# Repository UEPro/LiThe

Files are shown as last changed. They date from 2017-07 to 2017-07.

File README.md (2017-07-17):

# LiThe
Lichttheremin / Light-Theremin<br />

This PCB was designed for a Workshop in Germany, thus the documentation is in German. Contact me if you need a translation (Contact info in folder "Documentation", file "Anleitung_LiThe")

<b>AKF-WORKSHOP:</b></n>

Hallo ihr Lieben, ich hoffe ihr hattet alle ein tolles Festival und seid gut Heim gekommen. :)

Vielen Dank, dass ihr beim Workshop mitgemacht habt. Es hat mir riesigen Spaß gemacht, mit euch zu Arbeiten und ich hoffe auch ihr hattet Freude am basteln.

Solltet ihr irgendwelche Fragen oder Probleme haben, schreibt mir einfach über github oder schickt mir eine E-Mail (die Adresse steht in der Anleitung oben im Ordner "Documentation").

Ich werde außerdem eine Facebookseite einrichten, damit ihr mich einfacher kontaktieren könnt. Der Link dazu kommt dann hier her.

Schreibt mir gerne auch für weiteres Feedback und Vorschläge.

Nochmals Danke für die tolle Zeit mit euch und das nette Feedback :) Ich hoffe man sieht sich wieder.

Downloadanleitung:<br />
-Einzelne Datei: Rechtsklick auf die Datei → "Ziel speichern unter" anklicken<br />
-Ganzes Archiv: oben rechts den grünen Knopf "Clone or download" anklicken → "Download as ZIP" anklicken → ZIP Archiv entpacken

<br /><span xmlns:dct="http://purl.org/dc/terms/" property="dct:title">LiThe</span> by <a xmlns:cc="http://creativecommons.org/ns#" href="https://github.com/UEPro/" property="cc:attributionName" rel="cc:attributionURL">Useless Electronics Projects</a> is licensed under a <a rel="license" href="http://creativecommons.org/licenses/by-sa/4.0/">Creative Commons Attribution-ShareAlike 4.0 International License</a>.<br />

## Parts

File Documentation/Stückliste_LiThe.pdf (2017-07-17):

## Lichttheremin – Bill of Materials (github.com/UEPro/LiThe)

Type | Manufacturer | Model | Specification | Package | Value | N | Part-Nr | Designators
Resistor | Royal Ohm | Metal film resistor | 0,6W; 250V; 50ppm/K | THT-axial | 100 Ω ±1% | 1 MF006FF1000A50 | | R2
Resistor | Royal Ohm | Metal film resistor | 0,6W; 250V; 50ppm/K | THT-axial | 10 kΩ ±1% | 1 MF006FF1002A50 | | R4
Resistor | Royal Ohm | Metal film resistor | 125mW; 150V= | SMD-0805 | 100 kΩ ±1% | 1 0805S8F1003T5E | | R3
Resistor | Token | LDR | | THT-radial | | 1 PGM5649D | | R1
Potentiometer | Alps | R12L | log. stereo | THT-radial | 10 kΩ | 1 RK12L12C0A0G | | VR1
Capacitor | Kemet | MLCC | 50V; X7R | THT 100mil | 10 nF ±20% | 1 C315C103M5R5TA | | C2
Capacitor | Kemet | MLCC | 50V; X7R | THT 200mil | 100 nF ±10% | 1 C322C104K5R5TA | | C3
Capacitor | Kemet | Polyester Capacitor | 63VAC; 100VDC | THT 200mil | 100 nF ±10% | 1 R82EC3100DQ70K | | C1
Capacitor | Wima | Polyester Capacitor | 63VAC; 100VDC | THT 200mil | 2,2 µF ±10% | 2 | MKS2D042201N00KO 00 | C4-5
Capacitor | Nichicon | Electrolytic Capacitor | 16V; ø6,3mm | THT-radial | 220 µF ±20% | 1 UVZ1C221MED | | C6
Diode | Diotec | ZMM4.7 | Z-Diode; 0,5W | MiniMELF | 4,7 V | 1 ZMM4.7 | | D1
Diode | Optosupply | LED | cyan 3mm | THT-radial | | 1 OSC34L3131A | | D2
Transistor | Fairchild | FDN304 | P-Ch. MOSFET | SOT-23 | | 1 FDN304P | | Q1
IC | TI | NE555 | | DIP-8 | | 1 NE555P | | U1
Switch | Generic | | SPDT Slide Switch | THT-radial | | 1 | | S1
Connector | Generic | Pin header | 1x2pin | THT 100mil | | 1 | | J1, J3
Connector | Generic | Pin header connector | 1x2pin | THT 100mil | | 1
Connector | Generic | Crimp Contacts | Female | | | 2
Connector | Lumberg | | Stereo 3,5mm TRS-Jack | THT | | 1 1503 07 | | J2
Connector | Generic | Battery Clip | 9V-Block | | | 1
PCB | | | | | | 1
Case | Gainta | | | | | 1 G1068B
Speaker | NOS | | 8ohm | | | 1
Battery | Duracell | 9V Industrial | 6LR61 | | | 1

NB: These are the parts I have used, mostly because I had them in stock. Other parts with other values/tolerances or from other manufacturers may work just as well or even better.

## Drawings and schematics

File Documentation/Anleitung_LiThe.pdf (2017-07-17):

# Lichttheremin

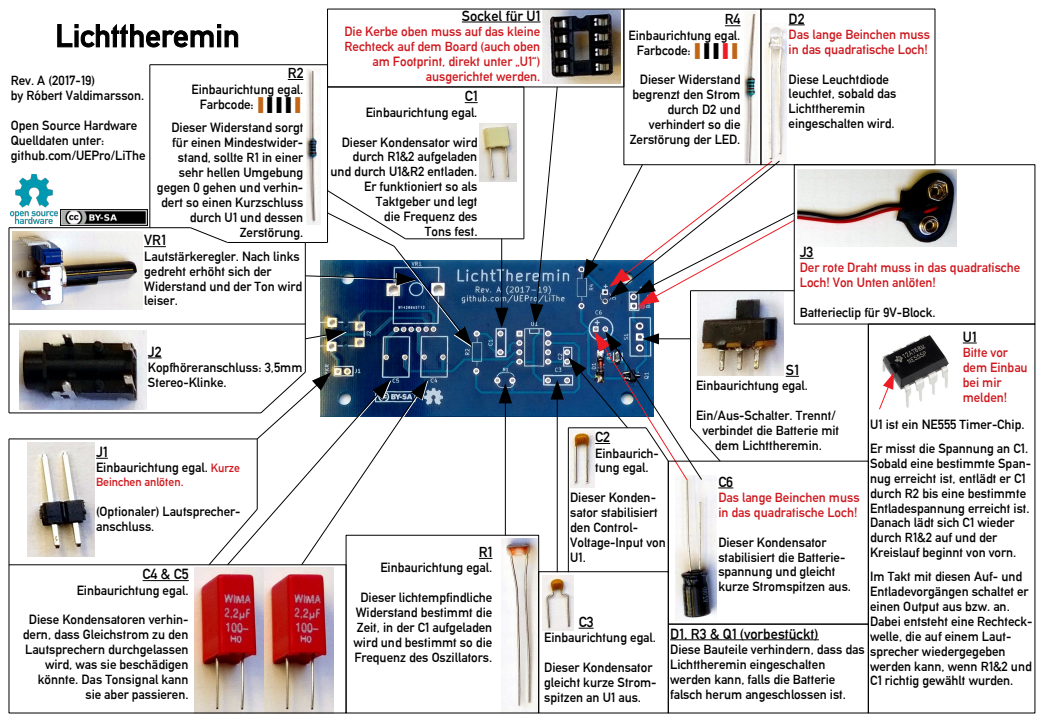
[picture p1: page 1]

Das lange Beinchen muss
in das quadratische Loch!

Die Kerbe oben muss auf das kleine
Rechteck auf dem Board (auch oben
am Footprint, direkt unter „U1“)

Einbaurichtung egal.
Farbcode:▐▐▐▐▐
Dieser Widerstand sorgt
für einen Mindestwider-
stand, sollte R1 in einer
sehr hellen Umgebung
gegen 0 gehen und verhin-
dert so einen Kurzschluss
durch U1 und dessen
Lautstärkeregler. Nach links
gedreht erhöht sich der
Widerstand und der Ton wird
leiser.

Open Source Hardware
Quelldaten unter:
github.com/UEPro/LiThe

Dieser Kondensator wird
durch R1&2 aufgeladen
und durch U1&R2 entladen.
Er funktioniert so als
Taktgeber und legt
die Frequenz des
Tons fest.

Der rote Draht muss in das quadratische
Loch! Von Unten anlöten!

Ein/Aus-Schalter. Trennt/
verbindet die Batterie mit
dem Lichttheremin.

U1 ist ein NE555 Timer-Chip.
Er misst die Spannung an C1.
Sobald eine bestimmte Span-
nug erreicht ist, entlädt er C1
durch R2 bis eine bestimmte
Entladespannung erreicht ist.
Danach lädt sich C1 wieder
durch R1&2 auf und der
Kreislauf beginnt von vorn.
Im Takt mit diesen Auf- und
Entladevorgängen schaltet er
einen Output aus bzw. an.
Dabei entsteht eine Rechteck-
welle, die auf einem Laut-
sprecher wiedergegeben
werden kann, wenn R1&2 und
C1 richtig gewählt wurden.

Dieser lichtempfindliche
Widerstand bestimmt die
Zeit, in der C1 aufgeladen
wird und bestimmt so die
Frequenz des Oszillators.

Diese Kondensatoren verhin-
dern, dass Gleichstrom zu den
Lautsprechern durchgelassen
wird, was sie beschädigen
könnte. Das Tonsignal kann

D1, R3 & Q1 (vorbestückt)
Diese Bauteile verhindern, dass das
Lichttheremin eingeschalten
werden kann, falls die Batterie
falsch herum angeschlossen ist.

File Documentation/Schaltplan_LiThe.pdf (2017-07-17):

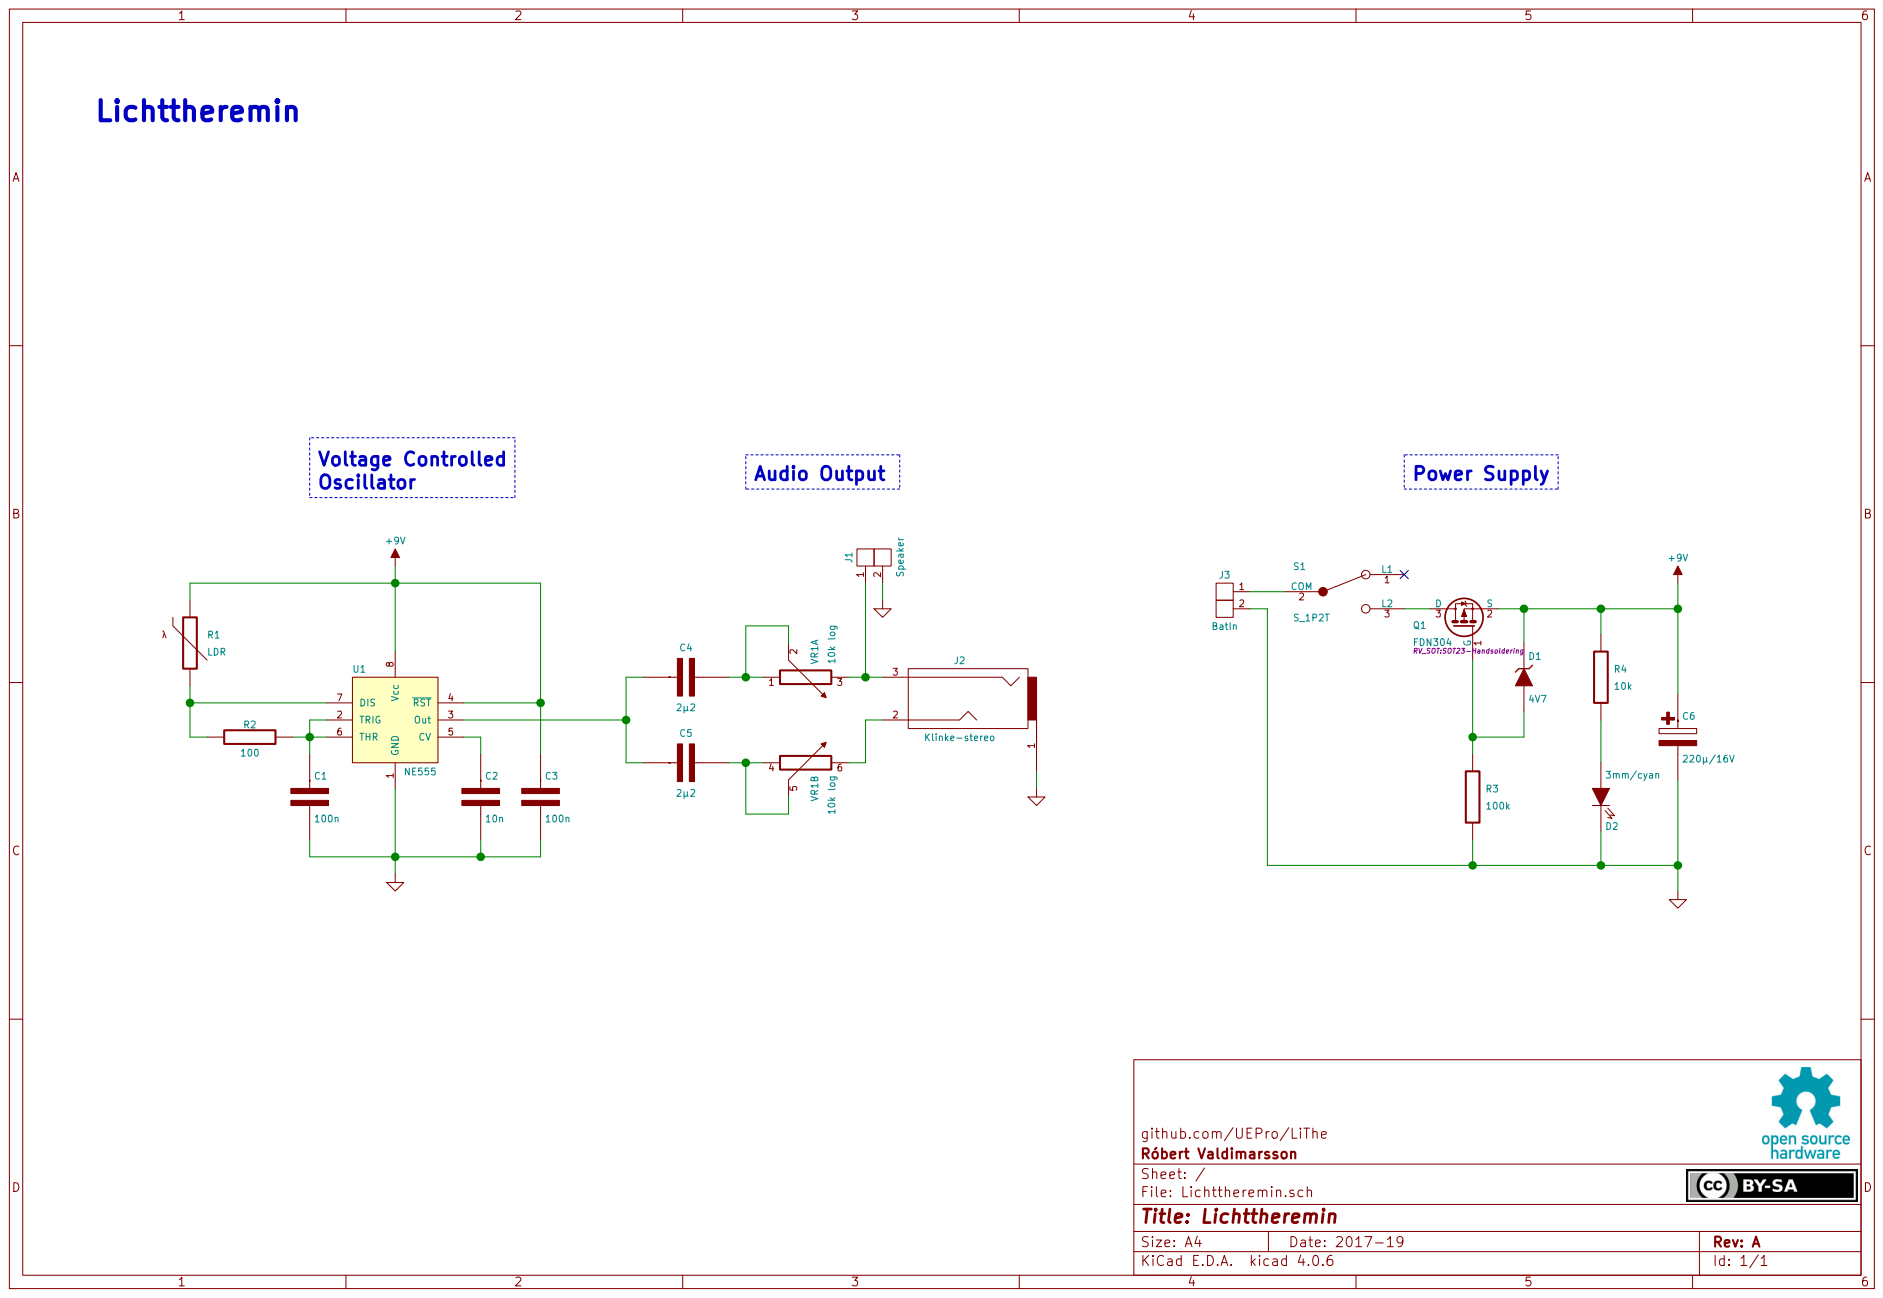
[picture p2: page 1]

1 TRIG 2 Out 3 RST 4 CV 5 THR 6 DIS 7 Vcc 8U1 NE555 C2

github.com/UEPro/LiThe
File: Lichttheremin.sch Sheet: / Róbert Valdimarsson

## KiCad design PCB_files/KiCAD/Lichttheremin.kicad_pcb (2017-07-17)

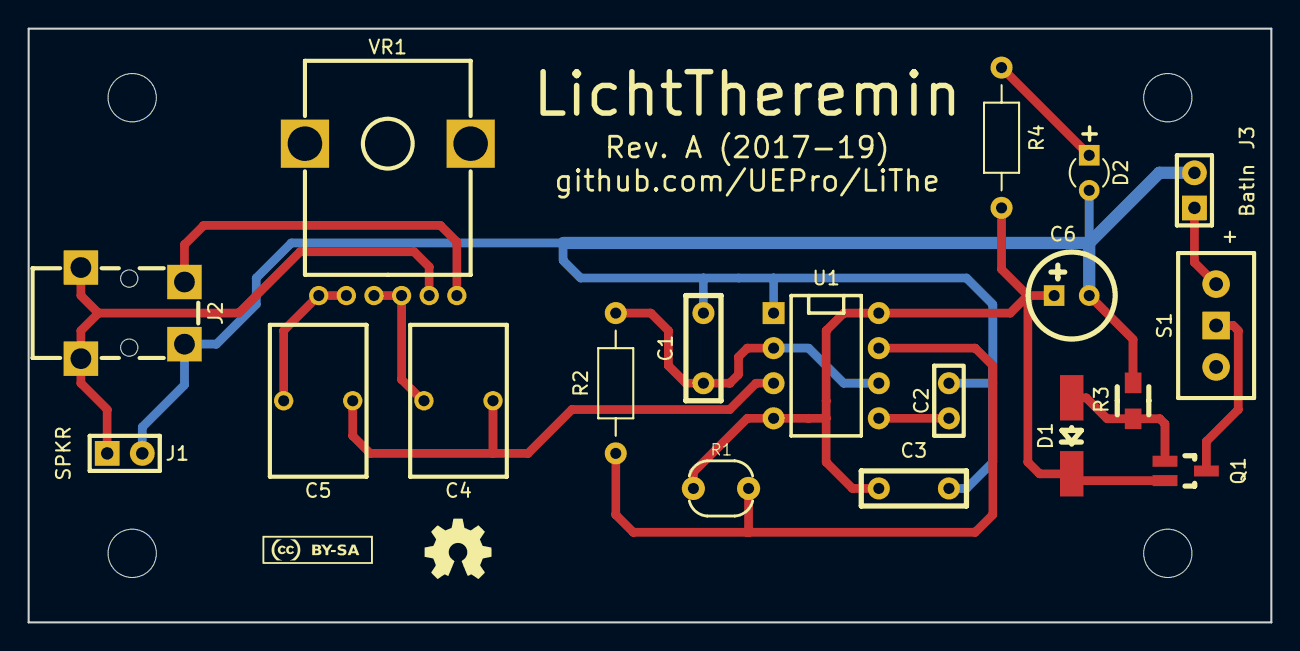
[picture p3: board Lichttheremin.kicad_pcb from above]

Board: 2 copper layers, 90.0 x 43.0 mm, 25 parts (0 on the bottom side), 14 nets.

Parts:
C1, C3: 100n; C_rect-radial-bipolar-200mil-2,5x7mm
C2: 10n; C_rect-radial-bipolar-100mil-2x5mm
C4, C5: 2µ2; C-Rect_L7_W11_P5
C6: 220µ/16V; C_round-radial-polar-2,5mm-6,3mm
D1: 4V7; Diode_MiniMELF-Handsoldering
D2: 3mm/cyan; LED_2pin-3mm
Des*: Val*; MountingHole-3,5mm
Des*#2, Des*#3, Des*#4: Val*; MountingHole-3,5mm
J1: Speaker; PinArray-100mil-1x2
J2: Klinke-stereo; Lumberg-1503-07-Klinke-3,5mm
J3: BatIn; PinArray-100mil-1x2
Q1: FDN304; SOT23-Handsoldering
R1: LDR; SparkFun-PHOTOCELL
R2: 100; R_axial_400mil
R3: 10k; SMD0805-HandSoldering
R4: 10k; R_axial_400mil
S1: S_1P2T; S-Schiebeschalter_China_SPDT
U1: NE555; DIP-8_300
VAL: REF; oshw5mm
VAL#2: REF; CC-BY-SA_08mm_Fsi
VR1: 10k log; VR-Alps_R12L_vert

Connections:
+9V: C3.1, C6.1, D1.2, Q1.2, R1.1, R4.1, U1.4, U1.8
GND: C1.2, C2.2, C3.2, C6.2, D2.2, J1.2, J2.1, J3.2, R3.2, U1.1
unnamed: C1.1, R2.2, U1.2, U1.6
unnamed: C2.1, U1.5
unnamed: C4.1, C5.1, U1.3
unnamed: C4.2, VR1.1, VR1.2
unnamed: C5.2, VR1.4, VR1.5
unnamed: D1.1, Q1.1, R3.1
unnamed: D2.1, R4.2
unnamed: J1.1, J2.3, VR1.3
unnamed: J2.2, VR1.6
unnamed: J3.1, S1.3
unnamed: Q1.3, S1.2
unnamed: R1.2, R2.1, U1.7
